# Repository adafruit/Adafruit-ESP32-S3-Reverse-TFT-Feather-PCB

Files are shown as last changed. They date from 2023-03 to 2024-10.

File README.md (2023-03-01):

## Adafruit ESP32-S3 Reverse TFT Feather - 4MB Flash, 2MB PSRAM, STEMMA QT PCB

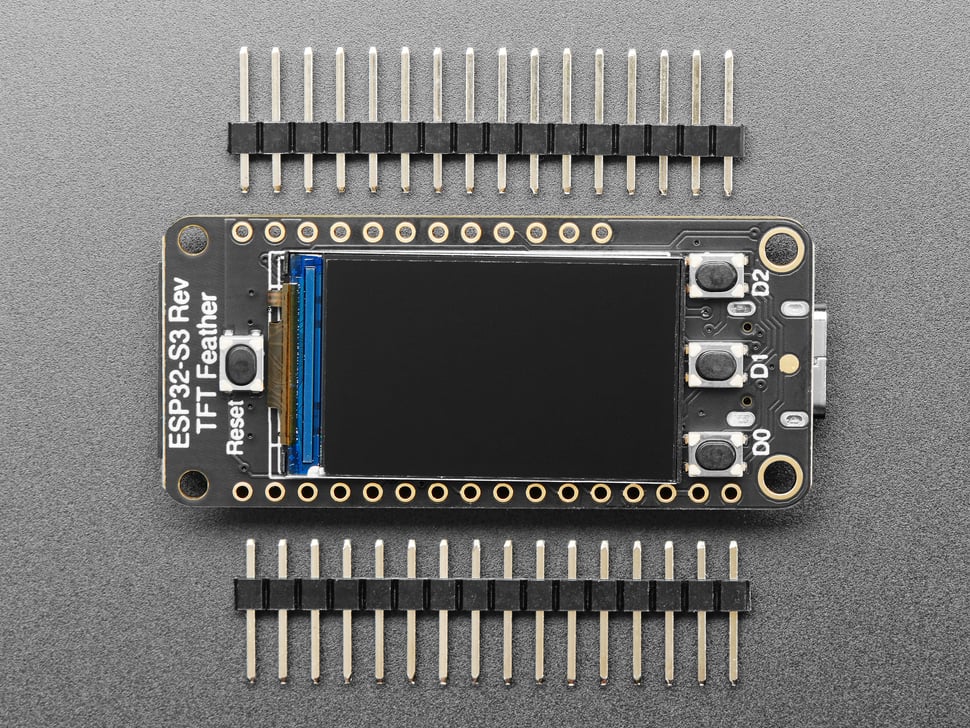
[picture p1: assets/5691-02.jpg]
<a href="http://www.adafruit.com/products/5691"><br/>
Click here to purchase one from the Adafruit shop</a>

PCB files for the Adafruit ESP32-S3 Reverse TFT Feather - 4MB Flash, 2MB PSRAM, STEMMA QT. 

Format is EagleCAD schematic and board layout
* https://www.adafruit.com/product/5691

### Description

Like Missy Elliot, we like to "put our [Feather] down, flip it and reverse it" and that's exactly what we've done with this new development board. It's basically our ESP32-S3 TFT Feather but with the 240x135 color TFT display on the back-side not the front-side. That makes it great for panel-mounted projects, particularly since we've also got some space for 3 buttons to go along. It's like an all-in-one display interface dev board, powered by the fantastic ESP32-S3 WIFI module.

This Feather comes with native USB and 4 MB Flash + 2 MB of PSRAM, so it is perfect for use with CircuitPython or Arduino with low-cost WiFi. Native USB means it can act like a keyboard or a disk drive. WiFi means it's awesome for IoT projects. And Feather means it works with the large community of Feather Wings for expandability.

The ESP32-S3 is a highly-integrated, low-power, 2.4 GHz Wi-Fi/BLE System-on-Chip (SoC) solution that has built-in native USB as well as some other interesting new technologies like Time of Flight distance measurements and AI acceleration. With its state-of-the-art power and RF performance, this SoC is an ideal choice for a wide variety of application scenarios relating to the Internet of Things (IoT), wearable electronics, and smart homes.

The Feather ESP32-S3 has a dual-core 240 MHz chip, so it is comparable to ESP32's dual-core. However, there is no Bluetooth Classic support, only Bluetooth LE. This chip is a great step up from the earlier ESP32-S2! This ESP32-S3 mini-module we are using on the Feather comes with 4 MB flash and 2 MB PSRAM, as well as lots of 512KB of SRAM so it's perfect for use with CircuitPython support or any time massive buffers are needed: for fast memory access use SRAM, for slower-but-roomier access use PSRAM. It's also great for use in ESP-IDF or with Arduino support.

The color TFT is connected to the SPI pins and uses additional pins for control that are not exposed to the breakout pads. It's the same display as you see here, with 240x135 pixels and is IPS so you get bright color at any angle. The backlight is also connected to a separate pin so you can PWM the backlight up and down as desired.

For low power usages, the Feather has a second low-dropout 3.3V regulator. The regulator is controlled with a GPIO pin on the enable line and can shut off power to the Stemma QT port and TFT. There is also a separate power pin for the NeoPixel that can be used to disable it for even lower quiescent power. With everything off and in deep sleep mode, the TFT feather uses about 100uA of current.

Features:

* ESP32-S3 Dual Core 240MHz Tensilica processor - the next generation of ESP32-Sx, with native USB so it can act like a keyboard/mouse, MIDI device, disk drive, etc!
* Mini module has FCC/CE certification and comes with 4 MByte of Flash and 2 MByte of PSRAM - you can have huge data buffers
* Color 1.14" IPS TFT with 240x135 pixels - bright and colorful display with ST7789 chipset that can be viewed at any angle angle.
* Three User Tactile buttons - D0, D1, and D2. D0/BOOT0 is also used for entering ROM bootloader mode if necessary.
* Power options - USB type C or Lipoly battery
* Built-in battery charging when powered over USB-C
* LiPoly battery monitor - MAX17048 chip actively monitors your battery for voltage and state of charge / percentage reporting over I2C
* Reset and DFU (BOOT0) buttons to get into the ROM bootloader (which is a USB serial port so you don't need a separate cable!)
* Serial debug output pin (optional, for checking the hardware serial debug console)
* STEMMA QT connector for I2C devices, with switchable power, so you can go into low power mode.
* On/Charge/User LEDs + status NeoPixel with pin-controlled power for low power usage
* Low Power friendly! In deep sleep mode, we can get down to 40~50uA of current draw from the Lipoly connection. Quiescent current is from the power regulator, ESP32-S2 chip, and Lipoly monitor. Turn off the NeoPixel and external I2C/TFT power for the lowest quiescent current draw.
* Works with Arduino or CircuitPython

### License

Adafruit invests time and resources providing this open source design, please support Adafruit and open-source hardware by purchasing products from [Adafruit](https://www.adafruit.com)!

Designed by Limor Fried/Ladyada for Adafruit Industries.

Creative Commons Attribution/Share-Alike, all text above must be included in any redistribution. 
See license.txt for additional details.

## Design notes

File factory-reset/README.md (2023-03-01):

## Factory Reset file - ESP32-S3 Reverse TFT Feather - 4MB Flash, 2MB PSRAM, STEMMA QT

This is the factory reset file for the ESP32-S3 Reverse TFT Feather - 4MB Flash, 2MB PSRAM, STEMMA QT.

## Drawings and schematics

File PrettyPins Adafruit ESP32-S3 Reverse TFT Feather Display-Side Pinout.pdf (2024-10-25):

# Adafruit ESP32-S3 Reverse TFT Feather Display-Side

# https://www.adafruit.com/product/5691

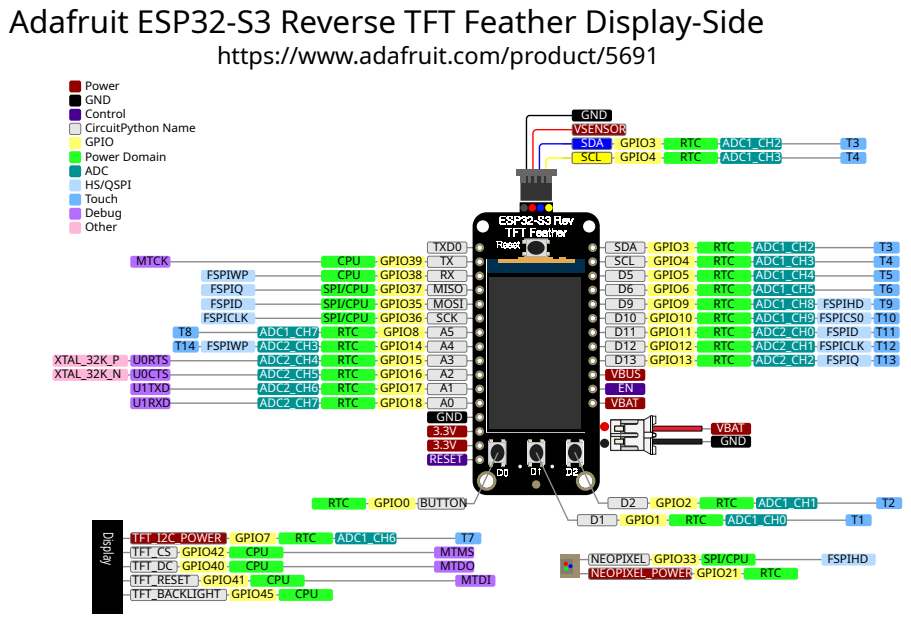
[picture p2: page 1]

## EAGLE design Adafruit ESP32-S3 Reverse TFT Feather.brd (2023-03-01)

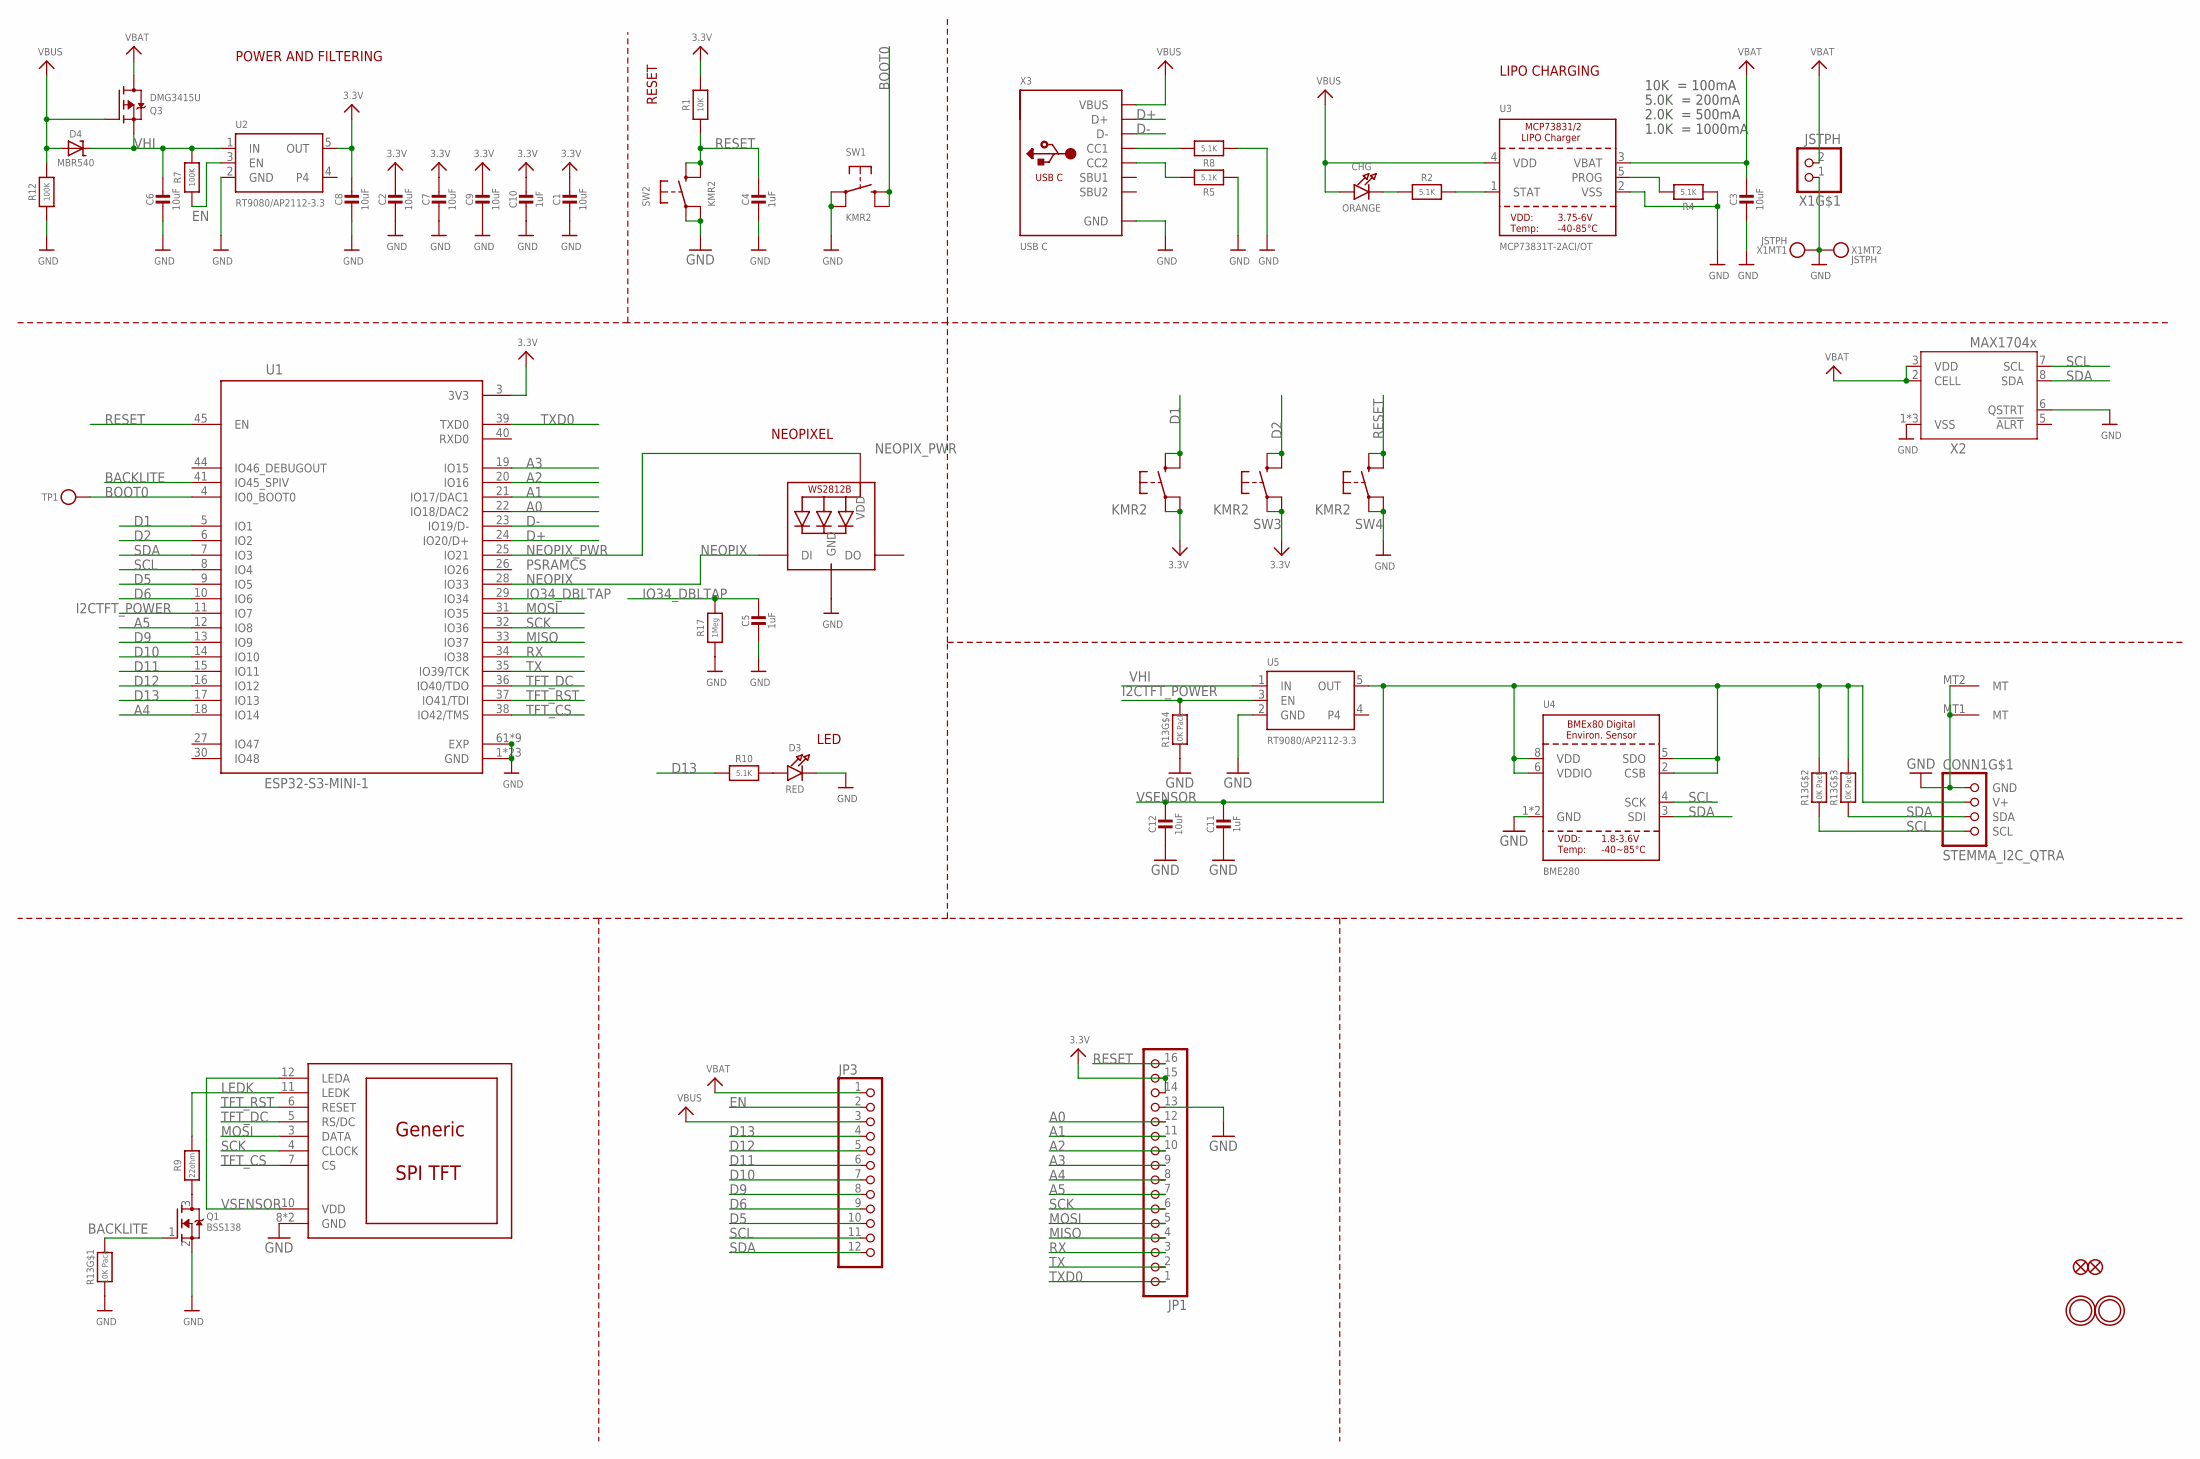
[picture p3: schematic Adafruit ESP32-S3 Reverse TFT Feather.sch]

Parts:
C1, C2, C3, C6, C7, C8, C9, C12: 10uF; 0805-NO
C4, C5, C10, C11: 1uF; 0603-NO
CHG: ORANGE; CHIPLED_0603_NOOUTLINE
CONN1: STEMMA_I2C_QTRA; JST_SH4_RA
D3: RED; CHIPLED_0603_NOOUTLINE
D4: MBR540; SOD-123
DISP1: DISP_LCD_GENERIC_SPI_1.14IN_240X135_WRAPUNDER; TFT_1.14IN_240X135_WRAPUNDER
JP1: HEADER-1X16_MIN; 1X16_ROUND_MIN
JP3: HEADER-1X12_MIN; 1X12_ROUND_MIN
LED1: WS2812B_SK6805_1515; SK6805_1515
Q1: BSS138; SC70
Q3: DMG3415U; SOT23-R
R1: 10K; 0603-NO
R2, R4, R5, R8, R10: 5.1K; 0603-NO
R7, R12: 100K; 0603-NO
R9: 22ohm; 0603-NO
R13: 10K Pack; RESPACK_4X0603
R17: 1Meg; 0603-NO
SW1, SW2, SW3, SW4, SW5: KMR2; BTN_RKB2_4.6X2.8
TP1: TESTPOINTROUND1.5MMNO; TESTPOINT_ROUND_1.5MM_NO
U1: ESP32-S3-MINI-1; ESP32-S2-MINI-1
U2, U5: RT9080/AP2112-3.3; SOT23-5; JLC_ROTATION 0
U3: MCP73831T-2ACI/OT; SOT23-5
U4: BME280
U$31, U$32: MOUNTINGHOLE2.5; MOUNTINGHOLE_2.5_PLATED
U$34, U$35: FIDUCIAL_1MM
X1: JSTPH; JSTPH2_BATT
X2: MAX17048/T; TDFN8_2X2MM
X3: USB C; USB_C_CUSB31-CFM2AX-01-X

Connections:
3.3V: C1.1, C2.1, C7.1, C8.1, C9.1, C10.1, JP1.14, JP1.15, R1.2, SW3.A, SW3.A' (P1), SW5.A, SW5.A' (P1), U1.3 (3V3), U2.5 (OUT)
A0: JP1.12, U1.22 (IO18/DAC2)
A1: JP1.11, U1.21 (IO17/DAC1)
A2: JP1.10, U1.20 (IO16)
A3: JP1.9, U1.19 (IO15)
A4: JP1.8, U1.18 (IO14)
A5: JP1.7, U1.12 (IO8)
BACKLITE: Q1.1 (G), R13.8 (2), U1.41 (IO45_SPIV)
BOOT0: SW1.B (S), SW1.B' (S1), TP1.P$1, U1.4 (IO0_BOOT0)
D1: SW5.B (S), SW5.B' (S1), U1.5 (IO1)
D2: SW3.B (S), SW3.B' (S1), U1.6 (IO2)
D5: JP3.10, U1.9 (IO5)
D6: JP3.9, U1.10 (IO6)
D9: JP3.8, U1.13 (IO9)
D10: JP3.7, U1.14 (IO10)
D11: JP3.6, U1.15 (IO11)
D12: JP3.5, U1.16 (IO12)
D13: JP3.4, R10.1, U1.17 (IO13)
D+: U1.24 (IO20/D+), X3.A6 (D+), X3.B6 (D+)
D-: U1.23 (IO19/D-), X3.A7 (D-), X3.B7 (D-)
EN: JP3.2, R7.1, U2.3 (EN)
GND: C1.2, C2.2, C3.2, C4.2, C5.2, C6.2, C7.2, C8.2, C9.2, C10.2, C11.2, C12.2, CONN1.1 (GND), CONN1.MT1 (MT), CONN1.MT2 (MT), D3.C, DISP1.8 (GND), DISP1.13 (GND), JP1.13, LED1.4 (GND), Q1.2 (S), R4.1, R5.1, R8.1, R12.1, R13.1, R13.4 (1), R17.1, SW1.A, SW1.A' (P1), SW2.A, SW2.A' (P1), SW4.A, SW4.A' (P1), U1.1 (GND), U1.2 (GND), U1.42 (GND), U1.43 (GND), U1.46 (GND), U1.47 (GND), U1.48 (GND), U1.49 (GND), U1.50 (GND), U1.51 (GND), U1.52 (GND), U1.53 (GND), U1.54 (GND), U1.55 (GND), U1.56 (GND), U1.57 (GND), U1.58 (GND), U1.59 (GND), U1.60 (GND), U1.61 (EXP), U1.62 (GND), U1.63 (GND), U1.64 (GND), U1.65 (GND), U1.66 (EXP), U1.67 (EXP), U1.68 (EXP), U1.69 (EXP), U1.70 (EXP), U1.71 (EXP), U1.72 (EXP), U1.73 (EXP), U2.2 (GND), U3.2 (VSS), U4.1 (GND), U4.7 (GND), U5.2 (GND), X1.1, X1.NC1, X1.NC2, X2.1 (VSS), X2.4 (VSS), X2.6 (QSTRT), X2.THERMAL (VSS), X3.A1B12 (GND), X3.B1A12 (GND)
I2CTFT_POWER: R13.5 (2), U1.11 (IO7), U5.3 (EN)
IO34_DBLTAP: C5.1, R17.2, U1.29 (IO34)
LEDK: DISP1.11 (LEDK), R9.2
MISO: JP1.4, U1.33 (IO37)
MOSI: DISP1.3 (DATA), JP1.5, U1.31 (IO35)
unnamed: CHG.C, R2.1
unnamed: Q1.3 (D), R9.1
unnamed: R2.2, U3.1 (STAT)
unnamed: R4.2, U3.5 (PROG)
unnamed: D3.A, R10.2
unnamed: R8.2, X3.A5 (CC1)
unnamed: R5.2, X3.B5 (CC2)
NEOPIX: LED1.1 (DI), U1.28 (IO33)
NEOPIX_PWR: LED1.2 (VDD), U1.25 (IO21)
RESET: C4.1, JP1.16, R1.1, SW2.B (S), SW2.B' (S1), SW4.B (S), SW4.B' (S1), U1.45 (EN)
RX: JP1.3, U1.34 (IO38)
SCK: DISP1.4 (CLOCK), JP1.6, U1.32 (IO36)
SCL: CONN1.4 (SCL), JP3.11, R13.2 (1), U1.8 (IO4), U4.4 (SCK), X2.7 (SCL)
SDA: CONN1.3 (SDA), JP3.12, R13.3 (1), U1.7 (IO3), U4.3 (SDI), X2.8 (SDA)
TFT_CS: DISP1.7 (CS), U1.38 (IO42/TMS)
TFT_DC: DISP1.5 (RS/DC), U1.36 (IO40/TDO)
TFT_RST: DISP1.6 (RESET), U1.37 (IO41/TDI)
TX: JP1.2, U1.35 (IO39/TCK)
TXD0: JP1.1, U1.39 (TXD0)
VBAT: C3.1, JP3.1, Q3.3 (D), U3.3 (VBAT), X1.2, X2.2 (CELL), X2.3 (VDD)
VBUS: CHG.A, D4.A, JP3.3, Q3.1 (G), R12.2, U3.4 (VDD), X3.A4B9 (VBUS), X3.B4A9 (VBUS)
VHI: C6.1, D4.C, Q3.2 (S), R7.2, U2.1 (IN), U5.1 (IN)
VSENSOR: C11.1, C12.1, CONN1.2 (V+), DISP1.10 (VDD), DISP1.12 (LEDA), R13.6 (2), R13.7 (2), U4.2 (CSB), U4.5 (SDO), U4.6 (VDDIO), U4.8 (VDD), U5.5 (OUT)

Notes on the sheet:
POWER AND FILTERING
RESET
10K = 100mA
5.0K = 200mA
2.0K = 500mA
1.0K = 1000mA
LIPO CHARGING
LED
PSRAMCS
NEOPIXEL

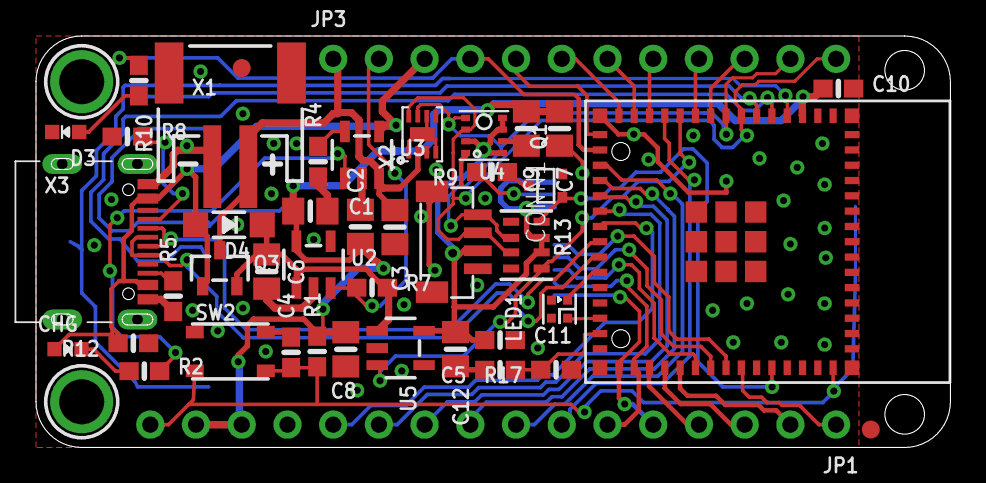
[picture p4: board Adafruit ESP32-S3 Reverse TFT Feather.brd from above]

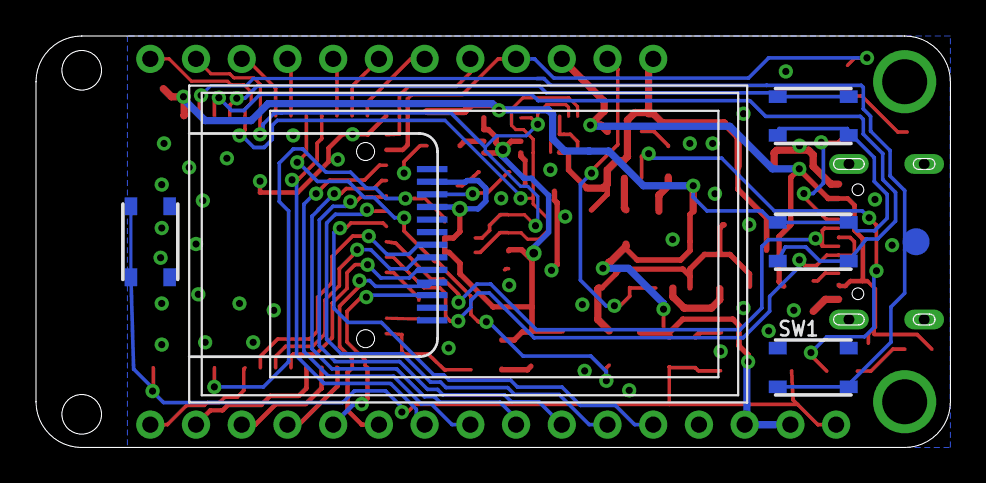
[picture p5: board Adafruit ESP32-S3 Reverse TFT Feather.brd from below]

Board: 2 copper layers, 50.8 x 22.9 mm, 88 parts (11 on the bottom side), 50 nets.

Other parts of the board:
PLABEL0: PLABEL0
PLABEL1: PLABEL1
PLABEL2: PLABEL2
PLABEL3: PLABEL3
PLABEL4: PLABEL4
PLABEL5: PLABEL5
PLABEL6: PLABEL6
PLABEL7: PLABEL7
PLABEL8: PLABEL8
PLABEL9: PLABEL9
PLABEL10: PLABEL10
PLABEL11: PLABEL11
PLABEL12: PLABEL12
PLABEL13: PLABEL13
PLABEL14: PLABEL14
PLABEL15: PLABEL15
PLABEL16: PLABEL16
PLABEL17: PLABEL17
PLABEL18: PLABEL18
PLABEL19: PLABEL19
PLABEL20: PLABEL20
PLABEL21: PLABEL21
PLABEL22: PLABEL22
PLABEL23: PLABEL23
PLABEL24: PLABEL24
PLABEL25: PLABEL25
PLABEL26: PLABEL26
PLABEL27: PLABEL27
PLABEL28: PLABEL28
PLABEL29: PLABEL29
PLABEL30: PLABEL30
PLABEL31: PLABEL31
PLABEL33: PLABEL33
PLABEL34: PLABEL34
PLABEL35: PLABEL35
PLABEL36: PLABEL36
PLABEL37: PLABEL37

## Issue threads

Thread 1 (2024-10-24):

Battery Connector Colors in Pretty Pins TopSide

mikeysklar, 2024-10-24:
[forum issue](https://forums.adafruit.com/viewtopic.php?t=214404) from @Timeline

The battery connector colors are at a diagonal from each other in the red <--> black when viewing the 2-pin battery JST connector DISPLAY SIDE. Swapping the black and red dots would make things correct.

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

ladyada, 2024-10-25:
@BlitzCityDIY plz work with @FoamyGuy to have him fix it! (good ez thing)

BlitzCityDIY, 2024-10-25:
will do! @FoamyGuy when you're working next ping me and we'll chat

FoamyGuy, 2024-10-25:
This is updated now, thanks for reporting! I left a comment in the linked forum post as well.

Closed 2024-10-25.

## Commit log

2023-03-01 adding cookiecutter output
    [Adafruit ESP32-S3 Reverse TFT.brd, Adafruit ESP32-S3 Reverse TFT.sch]
2023-03-01 updating eagle file names
    [Adafruit ESP32-S3 Reverse TFT Feather.brd, Adafruit ESP32-S3 Reverse TFT Feather.sch]
2023-10-31 updating factory reset
    more responsive buttons
2024-10-25 correct red and black dots next to battery charge connector
2025-09-23 Correct battery connector

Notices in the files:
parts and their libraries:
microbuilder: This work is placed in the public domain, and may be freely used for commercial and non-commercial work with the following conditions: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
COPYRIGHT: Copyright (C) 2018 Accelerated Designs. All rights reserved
